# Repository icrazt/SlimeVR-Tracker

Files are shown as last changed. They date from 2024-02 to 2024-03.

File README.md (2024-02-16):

# SlimeVR-Tracker  CC Version

Crazt 的小体积 SlimeVR 硬件方案

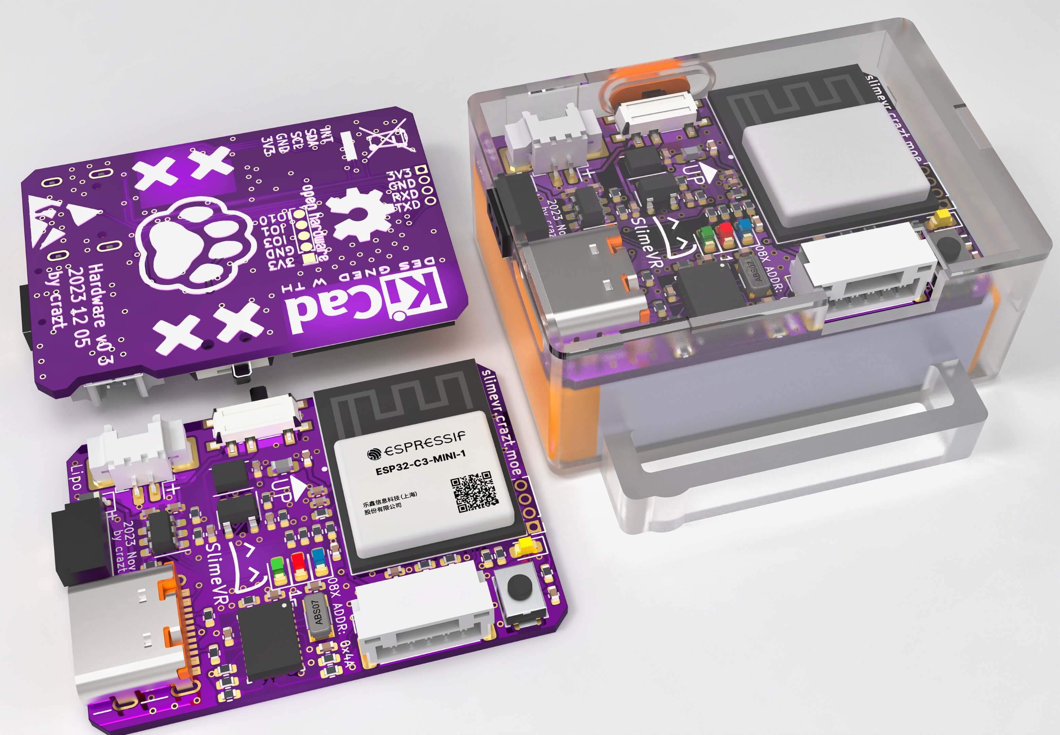
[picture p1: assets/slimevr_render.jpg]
slimevr_render


## Components

主要器件选型：

| Main Component | Specification | Note |
| --- | --- | --- |
| SoC Module | ESP32-C3-MINI-1 | |
| IMU | BNO085 | IMU Comparison [BNO085](https://docs.slimevr.dev/diy/imu-comparison.html#bno085) |
| Charging | LGS4084HB6 | 400 mA charging current |
| Power Supply | SY8088IAAC | step down DC/DC regulator，1A output current |
| Battery | 1000mAh polymer lithium battery, | `35*25*10mm` (WxLxH) or 102535, Molex 1.25 2pin connector, 35mm lead length |

PCB 接口：

| Interfaces | Specification | Note |
| --- | --- | --- |
| USB | USB4105 - **Type C** USB 2.0 Connector | charging and firmware burning |
| Sub-tracking interface (AUX) | JST_GH_SM05B | self-locking connector |
| Pogo pin connector | 2 pin  2.5mm pitch | reserve for future charging hub |
| UART pad | 4 pin 1.25mm pitch | *first time  firmware burning |

补充说明：

1. 选用 ESP32-C3-MINI-1 小体积模组，搭载 RISC-V 32 位单核处理器，时钟频率高达 160 MHz。支持 [USB CDC  串口连接](https://www.espressif.com/sites/default/files/documentation/esp32-c3_technical_reference_manual_cn.pdf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)，无需添加其他芯片进行 USB-串口转换。
2. 电源部分使用 SY8088IAAC 1A 同步降压调节器，相比低压降(*LDO*) 稳压器效率更高，在搭配 1000mAh 电池时实测至少可用10小时
3. 电池管理部分选用 LGS4084HB6 线性充电芯片，在 400mAh 充电时温度稳定，不会因芯片结温过高触发保护
4. 外壳：FDM 3D 打印外壳 + 亚克力顶部盖板，胶水粘合
5. 绑带：推荐搭配 25mm 硅胶防滑魔术贴绑带使用
6. Pogo pin 连接器：为待设计的充电坞预留的弹簧式探针接口，目前未使用

## About PCB Project

PCB 工程使用 KiCAD 7.0.7 版本设计，如需编辑建议使用最新版本。

部分元件引用自我的个人元件库 [icrazt/crazt-kicad-library: Personal kicad library](https://github.com/icrazt/crazt-kicad-library)，建议修改工程前添加。

## Firmware

使用原版固件修改引脚和相关配置即可使用，引脚定义如下

```c
  #define PIN_IMU_SDA 5
  #define PIN_IMU_SCL 4
  #define PIN_IMU_INT 6
  #define PIN_IMU_INT_2 7
  #define PIN_BATTERY_LEVEL 0
  #define LED_PIN 8
```

可以直接通过我 fork 仓库中的个人分支构建适用于该硬件的固件：

[icrazt/SlimeVR-Tracker-ESP at dev_crazt](https://github.com/icrazt/SlimeVR-Tracker-ESP/tree/dev_crazt)

## Gallery



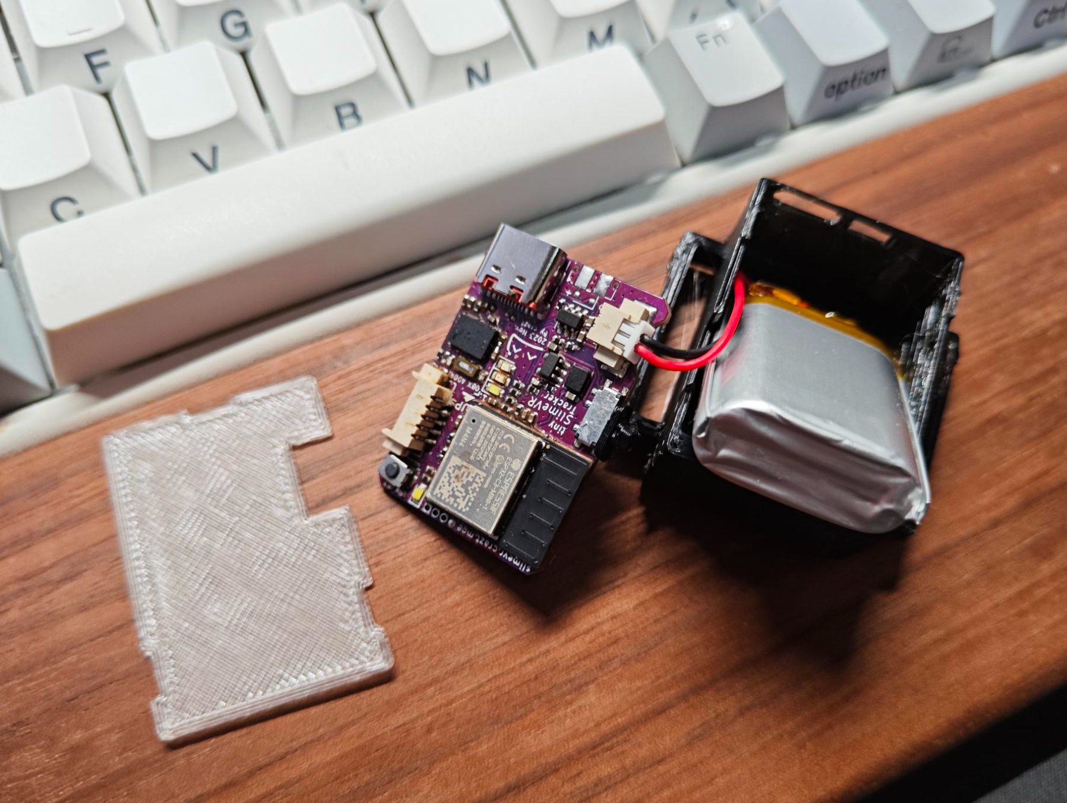
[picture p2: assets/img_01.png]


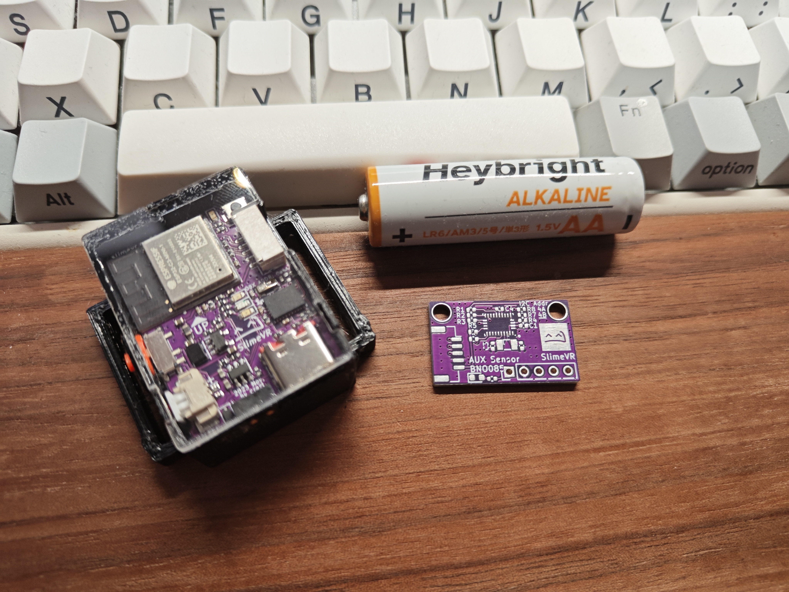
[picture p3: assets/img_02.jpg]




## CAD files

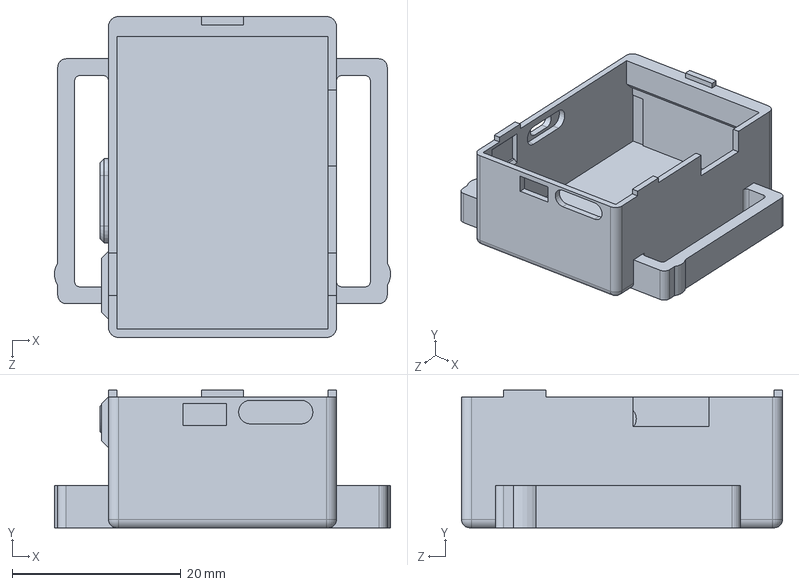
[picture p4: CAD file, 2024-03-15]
2.Mechanic/slimevr-tracker-tiny_mechanic/solidworks/slimevr_tiny_box.SLDPRT
39.8 x 16.3 x 38.0 mm

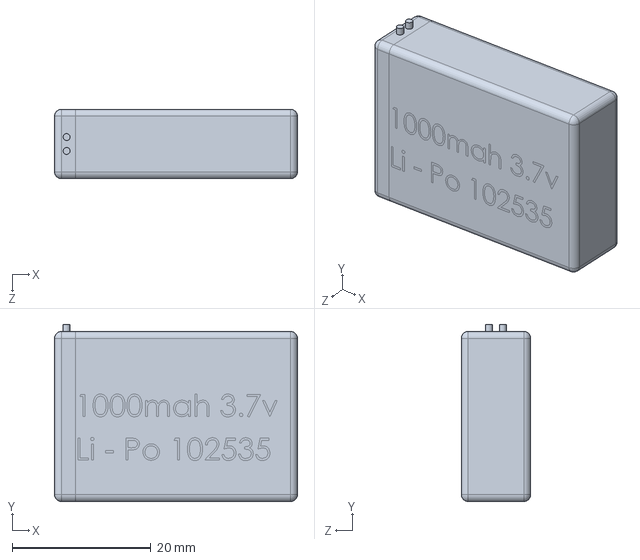
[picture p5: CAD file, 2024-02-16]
2.Mechanic/slimevr-tracker-tiny_mechanic/solidworks/1000mah_3.7v1s_102535_lipo.SLDPRT
35.0 x 25.5 x 10.0 mm

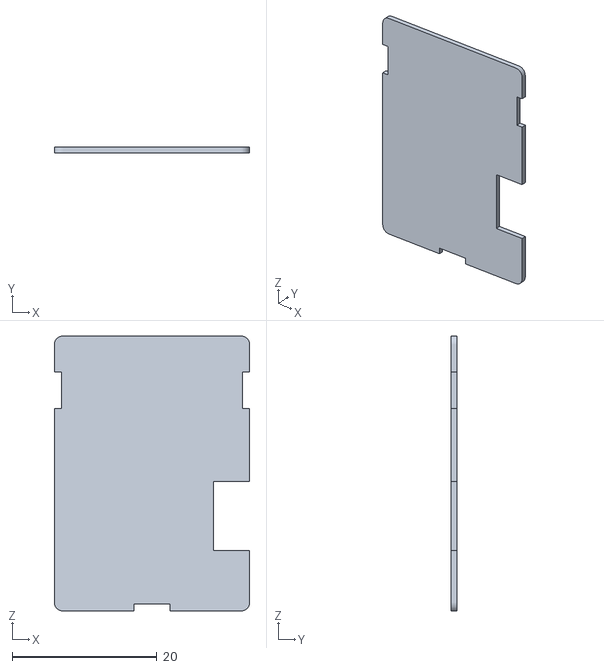
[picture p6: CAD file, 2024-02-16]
2.Mechanic/slimevr-tracker-tiny_mechanic/STL_for_3D_Print/slimevr_tiny_top.STL
27.0 x 0.8 x 38.0

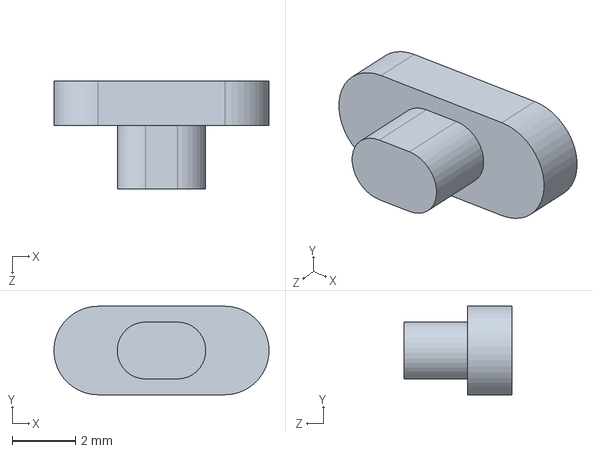
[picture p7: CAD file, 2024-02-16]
2.Mechanic/slimevr-tracker-tiny_mechanic/solidworks/slimevr_tiny_sw.SLDPRT
6.79 x 2.80 x 3.40 mm

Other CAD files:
2.Mechanic/slimevr-tracker-tiny_mechanic/STL_for_3D_Print/slimevr_tiny_box.STL
2.Mechanic/slimevr-tracker-tiny_mechanic/STL_for_3D_Print/slimevr_tiny_sw.STL
2.Mechanic/slimevr-tracker-tiny_mechanic/solidworks/slimevr_tiny_top.SLDPRT

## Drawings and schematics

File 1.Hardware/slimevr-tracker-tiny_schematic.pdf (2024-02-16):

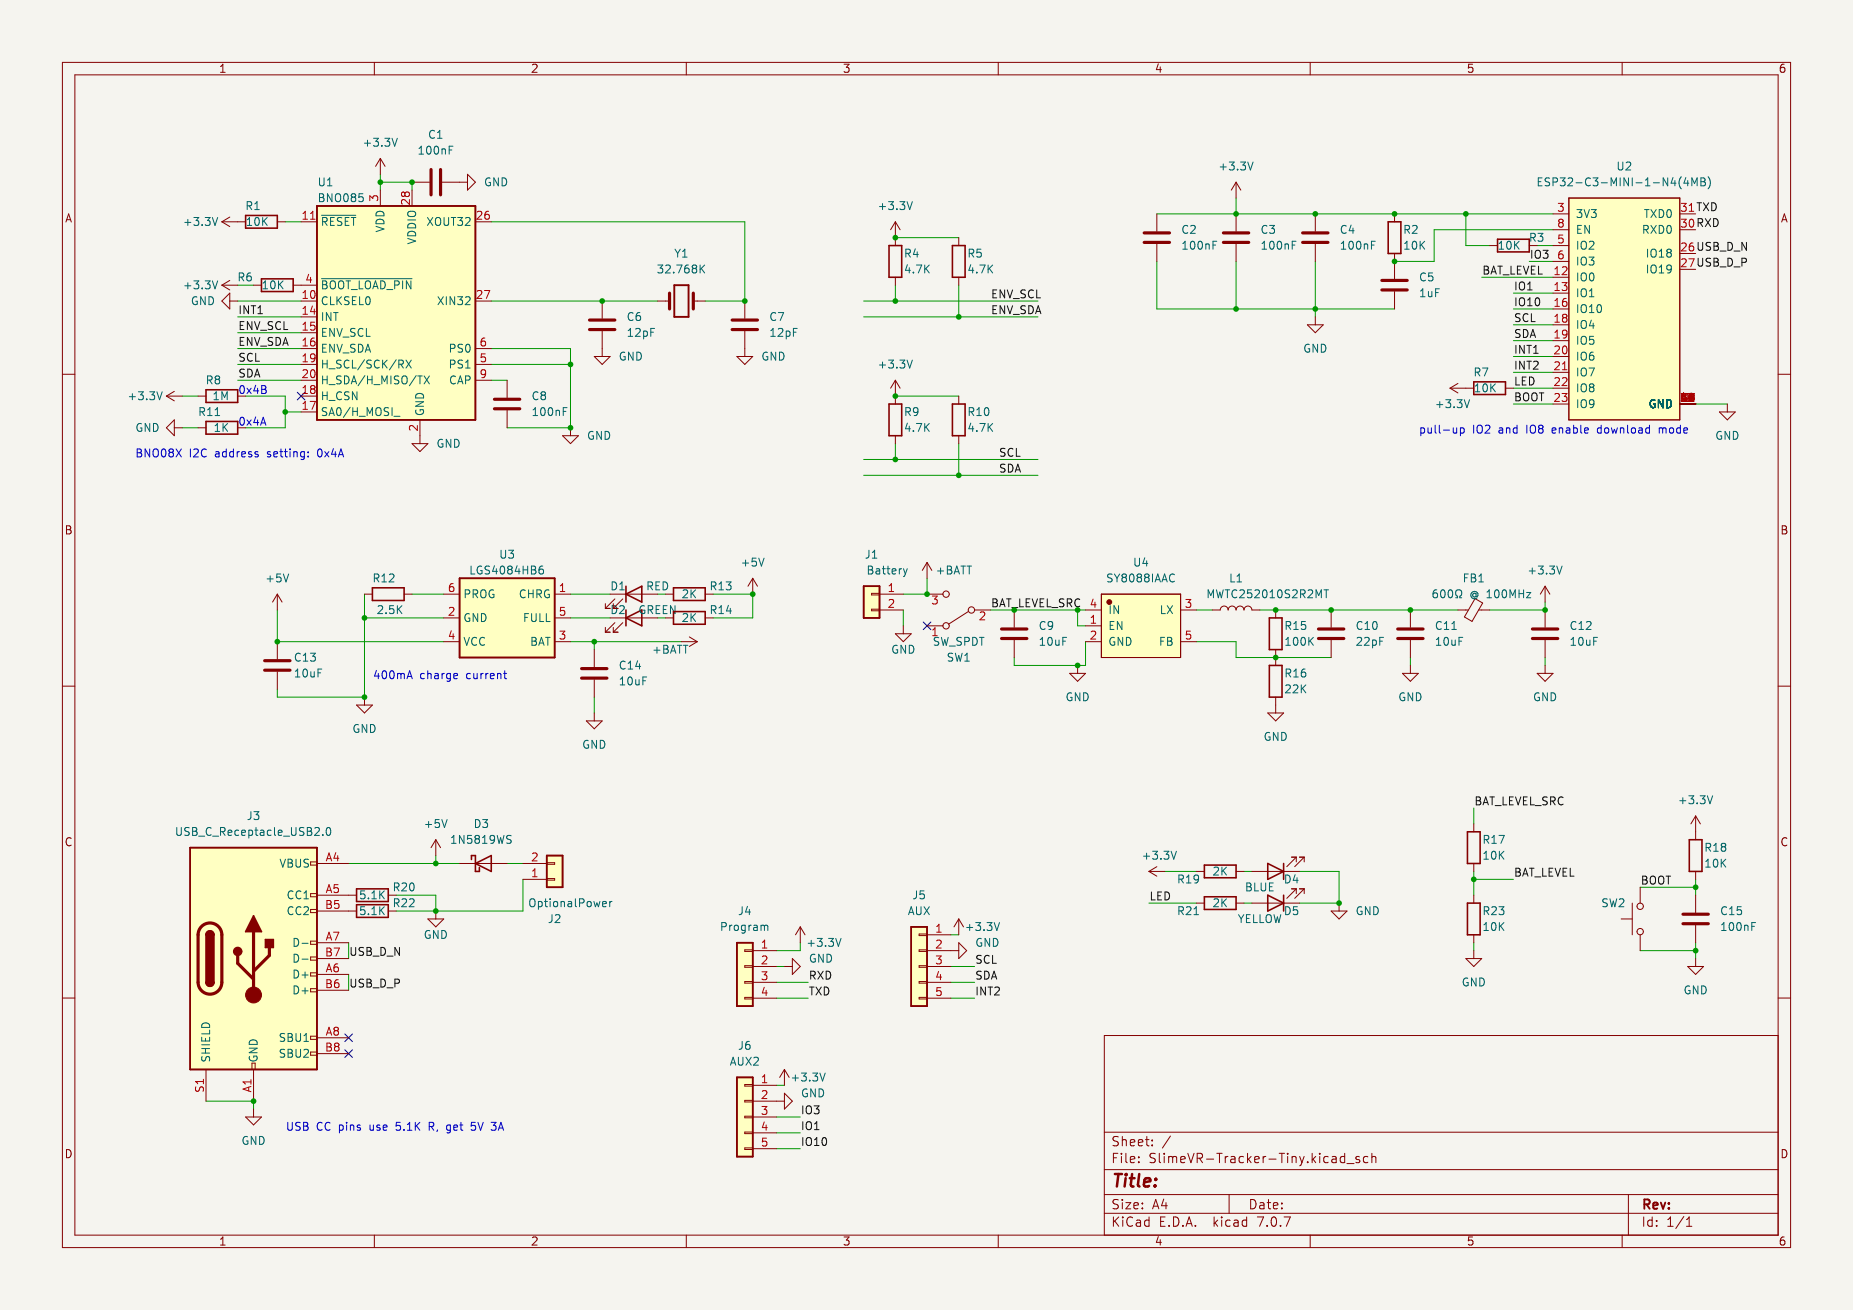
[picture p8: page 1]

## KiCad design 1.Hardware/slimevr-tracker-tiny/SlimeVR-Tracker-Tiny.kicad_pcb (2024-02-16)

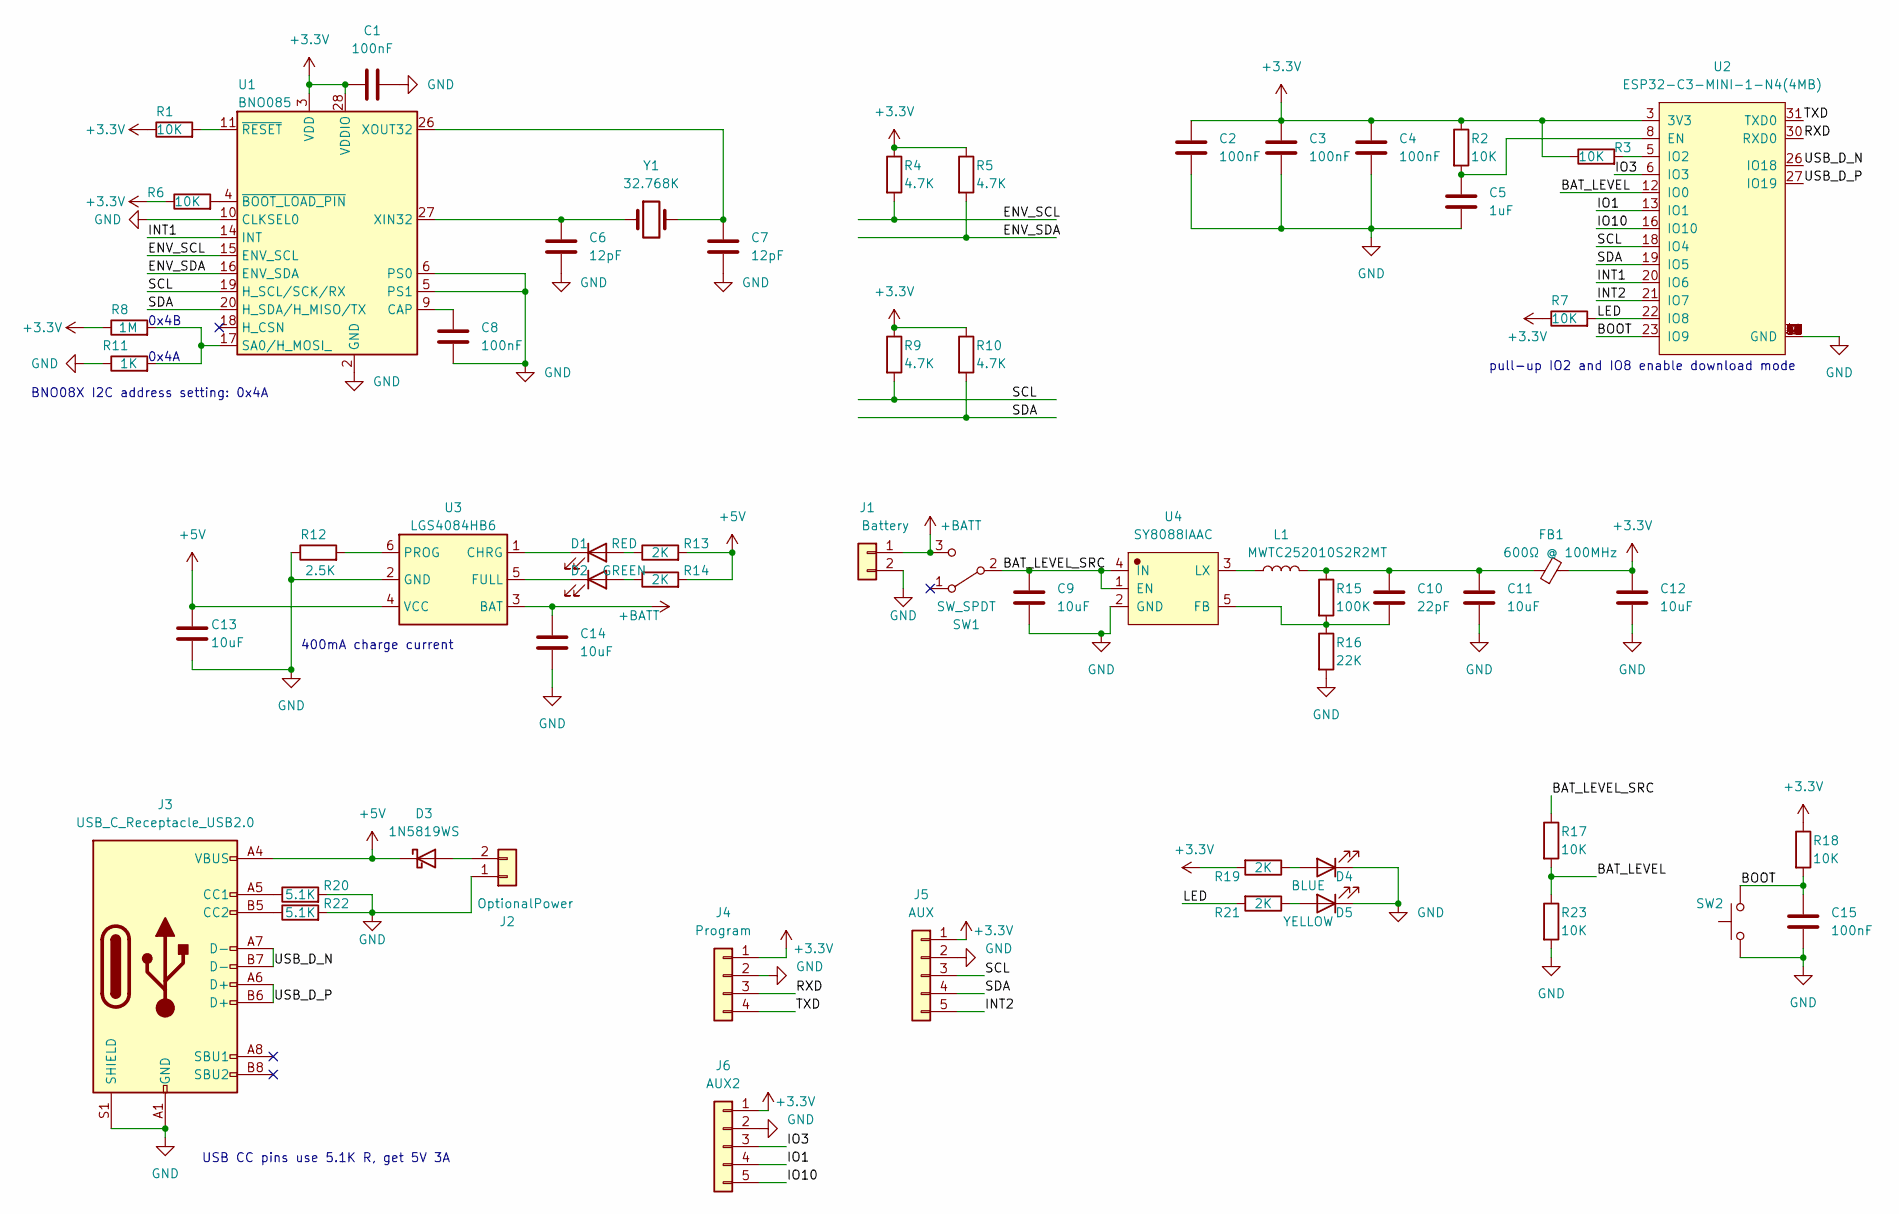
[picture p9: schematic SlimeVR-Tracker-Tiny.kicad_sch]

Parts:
C1, C2, C3, C4, C8, C15: 100nF; C_0402_1005Metric
C5: 1uF; C_0402_1005Metric
C6, C7: 12pF; C_0402_1005Metric
C9, C11, C12, C13, C14: 10uF; C_0402_1005Metric
C10: 22pF; C_0402_1005Metric
D1: RED; LED_0603_1608Metric
D2: GREEN; LED_0603_1608Metric
D3: 1N5819WS; D_SOD-323
D4: BLUE; LED_0603_1608Metric
D5: YELLOW; LED_0603_1608Metric
FB1: 600Ω @ 100MHz; L_0603_1608Metric
J1: Battery; Molex_PicoBlade_53261-0271_1x02-1MP_P1.25mm_Horizontal
J2: OptionalPower; YZ193115035T-02025-01
J3: USB_C_Receptacle_USB2.0; USB_C_Receptacle_GCT_USB4105-xx-A_16P_TopMnt_Horizontal
J4: Program; PinHeader_1x04_P1.27mm_Vertical
J5: AUX; JST_GH_SM05B-GHS-TB_1x05-1MP_P1.25mm_Horizontal
J6: AUX2; Pad_1x05_P1.27mm
L1: MWTC252010S2R2MT; L_Sunlord_SWPA252010S
R1, R2, R3, R6, R7, R17, R18, R23: 10K; R_0402_1005Metric
R4, R5, R9, R10: 4.7K; R_0402_1005Metric
R8: 1M; R_0402_1005Metric
R11: 1K; R_0402_1005Metric
R12: 2.5K; R_0402_1005Metric
R13, R14, R19, R21: 2K; R_0402_1005Metric
R15: 100K; R_0402_1005Metric
R16: 22K; R_0402_1005Metric
R20, R22: 5.1K; R_0402_1005Metric
SW1: SW_SPDT; SW_SPDT_PCM12
SW2: SW_Push; SW_Push_SPST_NO_Alps_SKRK
U1: BNO085; LGA-28_5.2x3.8mm_P0.5mm
U2: ESP32-C3-MINI-1-N4(4MB); WIFIM-SMD_ESP32-C3-MINI-1
U3: LGS4084HB6; SOT-23-6
U4: SY8088IAAC; SOT-23-5
Y1: 32.768K; Crystal_SMD_3215-2Pin_3.2x1.5mm

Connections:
+3.3V: C1.1, C2.1, C3.1, C4.1, C12.1, FB1.2, J4.1, J5.1, J6.1, R1.1, R2.1, R3.1, R4.1, R5.1, R6.1, R7.1, R8.1, R9.1, R10.1, R18.1, R19.2, U1.3 (VDD), U1.28 (VDDIO), U2.3 (3V3)
+5V: C13.1, D3.1 (K), J3.A4 (VBUS), J3.A9 (VBUS), J3.B4 (VBUS), J3.B9 (VBUS), R13.2, R14.2, U3.4 (VCC)
+BATT: C14.1, J1.1, SW1.3 (C), U3.3 (BAT)
/BAT_LEVEL: R17.2, R23.1, U2.12 (IO0)
/BAT_LEVEL_SRC: C9.1, R17.1, SW1.2 (B), U4.1 (EN), U4.4 (IN)
/BOOT: C15.1, R18.2, SW2.2, U2.23 (IO9)
/ENV_SCL: R4.2, U1.15 (ENV_SCL)
/ENV_SDA: R5.2, U1.16 (ENV_SDA)
/INT1: U1.14 (INT), U2.20 (IO6)
/INT2: J5.5, U2.21 (IO7)
/IO1: J6.4, U2.13 (IO1)
/IO3: J6.3, U2.6 (IO3)
/IO10: J6.5, U2.16 (IO10)
/LED: R7.2, R21.2, U2.22 (IO8)
/RXD: J4.3, U2.30 (RXD0)
/SCL: J5.3, R9.2, U1.19 (H_SCL/SCK/RX), U2.18 (IO4)
/SDA: J5.4, R10.2, U1.20 (H_SDA/H_MISO/TX), U2.19 (IO5)
/TXD: J4.4, U2.31 (TXD0)
/USB_D_N: J3.A7 (D-), J3.B7 (D-), U2.26 (IO18)
/USB_D_P: J3.A6 (D+), J3.B6 (D+), U2.27 (IO19)
GND: C1.2, C2.2, C3.2, C4.2, C5.2, C6.1, C7.1, C8.2, C9.2, C11.2, C12.2, C13.2, C14.2, C15.2, D4.1 (K), D5.1 (K), J1.2, J2.1, J3.A1 (GND), J3.A12 (GND), J3.B1 (GND), J3.B12 (GND), J3.S1 (SHIELD), J4.2, J5.2, J6.2, R11.1, R12.1, R16.2, R20.2, R22.2, R23.2, SW2.1, U1.2 (GND), U1.5 (PS1), U1.6 (PS0), U1.10 (CLKSEL0), U1.25 (GND), U2.1 (GND), U2.2 (GND), U2.11 (GND), U2.14 (GND), U2.36 (GND), U2.37 (GND), U2.38 (GND), U2.39 (GND), U2.40 (GND), U2.41 (GND), U2.42 (GND), U2.43 (GND), U2.44 (GND), U2.45 (GND), U2.46 (GND), U2.47 (GND), U2.48 (GND), U2.49 (GND), U2.50 (GND), U2.51 (GND), U2.52 (GND), U2.53 (GND), U3.2 (GND), U4.2 (GND)
unnamed: C10.1, C11.1, FB1.1, L1.2, R15.1
unnamed: D1.2 (A), R13.1
unnamed: D1.1 (K), U3.1 (CHRG)
unnamed: D2.2 (A), R14.1
unnamed: D2.1 (K), U3.5 (FULL)
unnamed: D3.2 (A), J2.2
unnamed: D4.2 (A), R19.1
unnamed: D5.2 (A), R21.1
unnamed: J3.A5 (CC1), R20.1
unnamed: J3.B5 (CC2), R22.1
unnamed: C8.1, U1.9 (CAP)
unnamed: R8.2, R11.2, U1.17 (SA0/H_MOSI_)
unnamed: C6.2, U1.27 (XIN32), Y1.1
unnamed: C7.2, U1.26 (XOUT32), Y1.2
unnamed: R6.2, U1.4 (~BOOT_LOAD_PIN)
unnamed: R1.2, U1.11 (~RESET)
unnamed: C5.1, R2.2, U2.8 (EN)
unnamed: R3.2, U2.5 (IO2)
unnamed: R12.2, U3.6 (PROG)
unnamed: C10.2, R15.2, R16.1, U4.5 (FB)
unnamed: L1.1, U4.3 (LX)

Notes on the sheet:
400mA charge current
BNO08X I2C address setting: 0x4A
pull-up IO2 and IO8 enable download mode
0x4A
USB CC pins use 5.1K R, get 5V 3A
0x4B

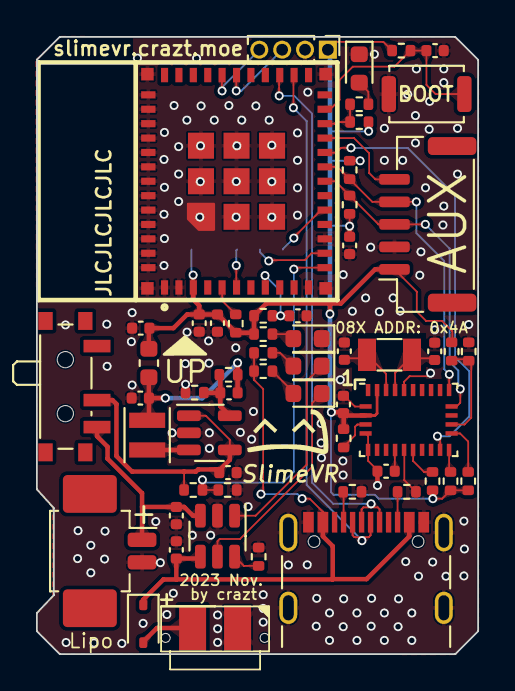
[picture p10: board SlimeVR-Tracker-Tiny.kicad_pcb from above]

Board: 2 copper layers, 24.5 x 34.3 mm, 58 parts (1 on the bottom side), 42 nets.

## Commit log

2024-02-16 First public release with v0.3 hardware that has been validated in real-world use.
    [1000mah_3.7v1s_102535_lipo.SLDPRT, SlimeVR-Tracker-Tiny.kicad_pcb, SlimeVR-Tracker-Tiny.kicad_sch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]
2024-03-15 [mechanic] revise tracker main box.
    [slimevr_tiny_box.SLDPRT, slimevr_tiny_box.STL]
